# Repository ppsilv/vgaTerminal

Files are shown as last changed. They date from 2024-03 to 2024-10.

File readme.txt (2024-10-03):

A ultima versão do github ficou desatualizada ou por algum motivo que desconheço não funciona mais
Por conta de que a versão 0.0.04 parou de funcionar sem que eu entendesse oque aconteceu resolvi fazer uma nova versão com o mesmo hardware.

Eu desconfio que os problemas foram com as atualizações da lib do bitluni ESP32Lib, assim eu coloquei a lib no diretório da aplicação e em Arduino/libraries eu coloquei um link simbólico para a lib que agora faz parte do projeto, assim eu consigo ficar livre das atualizações que o bitluni está fazendo.

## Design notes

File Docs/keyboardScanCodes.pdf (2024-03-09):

Next (https://www.win.tue.nl/~aeb/linux/kbd/scancodes-2.html) Previous Contents (https://www.win.tue.nl/~aeb/linux/kbd/scancodes.html#toc1)

### 1. Keyboard scancodes

The data from a keyboard comes mainly in the form of scancodes, produced by key presses or used in the protocol with the computer. ( Different codes (https://www.win.tue.nl/~aeb/linux/kbd/scancodes-10.html#scancodesets) are used by the keyboard firmware internally, and there also exist several sets of scancodes. (https://www.win.tue.nl/~aeb/linux/kbd/scancodes-10.html#scancodesets) Here in this section we only talk about the default codes - those from translated scancode set
2. Less common modes are discussed below.) (https://www.win.tue.nl/~aeb/linux/kbd/scancodes-10.html#scancodesets) Each key press and key release produces between 0 and 6 scancodes.

### 1.1 Key release

Below I'll only mention the scancode for key press (`make'). The scancode for key release (`break') is obtained from it by setting the high order bit (adding 0x80 = 128). Thus, Esc press produces scancode 01, Esc release scancode 81 (hex). For sequences things are similar: Keypad-/ gives e0 35 when pressed, e0 b5 when released. Most keyboards will repeat the make code (key down code) when the key repeats. Some will also fake Shift down and Shift up events during the repeat.

The keys PrtSc/SysRq and Pause/Break are special. The former produces
scancode e0 2a e0 37 when no modifier key is pressed simultaneously, e0 37 together with Shift or Ctrl, but 54 together with (left or right) Alt. (And one gets the expected sequences upon release. But see below.) (https://www.win.tue.nl/~aeb/linux/kbd/scancodes-5.html#mtek) The latter produces scancode
sequence e1 1d 45 e1 9d c5 when pressed (without modifier) and nothing at all upon release. However, together with (left or right) Ctrl, one gets e0 46 e0 c6, and again nothing at release. It does not repeat.

See below (https://www.win.tue.nl/~aeb/linux/kbd/scancodes-1.html#dellnoup) for a report on keys with a different behaviour.

There are many reports of laptops with badly debounced key-up events. Thus, unexpected key-up events should probably be regarded as not unusual, and be ignored. Another source of key-up events without preceding key-down can be the fake shift. (https://www.win.tue.nl/~aeb/linux/kbd/scancodes-1.html#fakeshifts)

### 1.2 Protocol scancodes

Most scancodes indicate a key press or release. Some are used in the communication protocol.

00 Keyboard error - see ff
aa | BAT (Basic Assurance Test) OK

ee | Result of echo command
f1 | Some keyboards, as reply to command a4:Password not installed
fa | Acknowledge from kbd
fc | BAT error or Mouse transmit error
fd | Internal failure
fe | Keyboard fails to ack, please resend
ff | Keyboard error

Three common causes for keyboard error are: (i) several keys pressed simultaneously, (ii) keyboard buffer overflow, (iii) parity error on the serial line used by keyboard and keyboard controller for communication. The error reported is ff in scancode mode (https://www.win.tue.nl/~aeb/linux/kbd/scancodes-10.html#scancodesets) 1, and 00 in scancode modes 2 and 3. If translation is on, both 00 and ff are translated as ff.

Usually these codes have the protocol meaning. However, they also occur as actual scancodes, especially when prefixed by e0.

### 1.3 Escape scancodes

The codes e0 and e1 introduce scancode sequences, and are not usually used as isolated scancodes themselves (but see below). (https://www.win.tue.nl/~aeb/linux/kbd/scancodes-7.html#e0_as_key)
(The prefix e0 was originally used for the grey duplicates of keys on the original PC/XT keyboard. These days e0 is just used to expand code space. The prefix e1 used for Pause/Break indicated that this key sends the make/break sequence at make time, and does nothing upon release.)
This, and the above, means that the values 00, 60, 61, 6e, 71, 7a, 7c, 7e, 7f are unavailable to signify key presses (on a default keyboard). Nevertheless they also occur as scancodes, see for example the Telerate (https://www.win.tue.nl/~aeb/linux/kbd/scancodes-2.html#telerate) and Safeway SW23 (https://www.win.tue.nl/~aeb/linux/kbd/scancodes-6.html#safeway23) keyboards below.

Also other prefixes occur, see below. (https://www.win.tue.nl/~aeb/linux/kbd/scancodes-5.html#prefix_80)
Logitech (https://www.win.tue.nl/~aeb/linux/kbd/scancodes-10.html#logiteche2) uses an e2 prefix for the codes sent by a pointing device integrated on the keyboard.

### 1.4 Ordinary scancodes

The scancodes in translated scancode set 2 are given in hex. Between parentheses the keycap on a US keyboard. The scancodes are given in order, grouped according to groups of keys that are usually found next to each other.

### 00 is normally an error code

01 (Esc)

02 (1!), 03 (2@), 04 (3#), 05 (4$), 06 (5%E), 07 (6^), 08 (7&), 09 (8*), 0a (9(), 0b (0 )), 0c (-_), 0d (=+), 0e (Backspace)

0f (Tab), 10 (Q), 11 (W), 12 (E), 13 (R), 14 (T), 15 (Y), 16 (U), 17 (I), 18 (O), 19 (P), 1a ([{), 1b (]})

1c (Enter)

1d (LCtrl)

1e (A), 1f (S), 20 (D), 21 (F), 22 (G), 23 (H), 24 (J), 25 (K), 26 (L), 27 (;:), 28 ('")

29 (`~)

2a (LShift)

2b (\|), on a 102-key keyboard

2c (Z), 2d (X), 2e (C), 2f (V), 30 (B), 31 (N), 32 (M), 33 (,<), 34 (.>), 35 (/?), 36 (RS hift)
37 (Keypad-*) or (*/PrtScn) on a 83/84-key keyboard

38 (LAlt), 39 (Space bar),

3a (CapsLock)

3b (F1), 3c (F2), 3d (F3), 3e (F4), 3f (F5), 40 (F6), 41 (F7), 42 (F8), 43 (F9), 44 (F10 )
45 (NumLock)

46 (ScrollLock)

47 (Keypad-7/Home), 48 (Keypad-8/Up), 49 (Keypad-9/PgUp)

4a (Keypad--)

4b (Keypad-4/Left), 4c (Keypad-5), 4d (Keypad-6/Right), 4e (Keypad-+)

4f (Keypad-1/End), 50 (Keypad-2/Down), 51 (Keypad-3/PgDn)

52 (Keypad-0/Ins), 53 (Keypad-./Del)

54 (Alt-SysRq) on a 84+ key keyboard

### 55 is less common; occurs e.g. as F11 on a Cherry G80-0777 keyboard, as F12 on a

Telerate keyboard, as PF1 on a Focus 9000 keyboard, and as FN on an IBM ThinkPad.

56 mostly on non-US keyboards. It is often an unlabelled key to the left (https://www.win.tue.nl/~aeb/linux/kbd/laser.jpg) or to the right (https://www.win.tue.nl/~aeb/linux/kbd/toshiba.jpg) of the left Alt key.

57 (F11), 58 (F12) both on a 101+ key keyboard

59-5a-...-7f are less common. Assignment is essentially random. Scancodes 55-
59 occur as F11-F15 on the Cherry G80-0777 (https://www.win.tue.nl/~aeb/linux/kbd/scancodes-2.html#cherry80) keyboard. Scancodes 59-5c occur on the RC930 (https://www.win.tue.nl/~aeb/linux/kbd/scancodes-5.html#RC930) keyboard. X calls 5d `KEY_Begin'. Scancodes 61-64 occur on
a Telerate (https://www.win.tue.nl/~aeb/linux/kbd/scancodes-2.html#telerate) keyboard. Scancodes 55, 6d, 6f, 73, 74, 77, 78, 79, 7a, 7b, 7c, 7e occur on the Focus 9000 (https://www.win.tue.nl/~aeb/linux/kbd/scancodes-5.html#focus) keyboard. Scancodes 65, 67, 69, 6b occur on a Compaq
Armada (https://www.win.tue.nl/~aeb/linux/kbd/scancodes-5.html#armada) keyboard. Scancodes 66-68, 73 occur on the Cherry G81-3000 (https://www.win.tue.nl/~aeb/linux/kbd/scancodes-5.html#cherry81) keyboard. Scancodes 70, 73, 79, 7b, 7d occur on a Japanese 86/106 keyboard. (https://www.win.tue.nl/~aeb/linux/kbd/scancodes-8.html#japanese)

Scancodes f1 and f2 occur on Korean keyboards. (https://www.win.tue.nl/~aeb/linux/kbd/scancodes-9.html#korean)

### 1.5 Escaped scancodes

Apart from the Pause/Break key, that has an escaped sequence starting with e1, the escape used is e0. Often, the codes are chosen in such a way that something meaningful happens when the receiver just discards the e0.

e0 1c (Keypad Enter) | 1c (Enter)
e0 1d (RCtrl) | 1d (LCtrl)
e0 2a (fake LShift) | 2a (LShift)
e0 35 (Keypad-/) | 35 (/?)
e0 36 (fake RShift) | 36 (RShift)
e0 37 (Ctrl-PrtScn) | 37 (*/PrtScn)
e0 38 (RAlt) | 38 (LAlt)
e0 46 (Ctrl-Break) | 46 (ScrollLock)
e0 47 (Grey Home) | 47 (Keypad-7/Home)
e0 48 (Grey Up) | 48 (Keypad-8/UpArrow)
e0 49 (Grey PgUp) | 49 (Keypad-9/PgUp)
e0 4b (Grey Left) | 4b (Keypad-4/Left)
e0 4d (Grey Right) | 4d (Keypad-6/Right)
e0 4f (Grey End) | 4f (Keypad-1/End)
e0 50 (Grey Down) | 50 (Keypad-2/DownArrow)
e0 51 (Grey PgDn) | 51 (Keypad-3/PgDn)
e0 52 (Grey Insert) | 52 (Keypad-0/Ins)
e0 53 (Grey Delete) | 53 (Keypad-./Del)

These escaped scancodes occur only on 101+ key keyboards. The Microsoft keyboard (https://www.win.tue.nl/~aeb/linux/kbd/scancodes-6.html#microsoft) adds

e0 5b (LeftWindow)
e0 5c (RightWindow)
e0 5d (Menu)

Other escaped scancodes occur - see below under the individual keyboards.

### 1.6 Fake shifts

The ten grey keys Insert, Home, PgUp, Delete, End, PgDn, Up, Left, Down, Right are supposed to function regardless of the state of Shift and NumLock keys. But for an old AT keyboard the keypad keys would produce digits when Numlock was on or Shift was down. Therefore, in order to fool old programs, fake scancodes are sent: when LShift is down, and Insert is pressed, e0 aa e0 52 is sent; upon release of Insert e0 d2 e0 2a is sent. In other words, a fake LShift-up and fake LShift-down are inserted.

If the Shift key is released earlier than the repeated key, then a real Shift-up code occurs (without preceding fake Shift-down) so that a program ignoring e0 would see one more Shift-up than Shift-down.

When NumLock is on, no fake Shifts are sent when Shift was down, but fake Shifts are sent when Shift was not down. Thus, with Numlock, if Insert is
pressed, e0 2a e0 52 is sent and upon release e0 d2 e0 aa is sent. The keyboard maintains a private NumLock mode, toggled when NumLock is pressed, and set when the NumLock LED is set.

In the same way, when Shift is down, the Grey-/ key produces fake Shift-up and fake Shift-down sequences. However, it does not react to the state of NumLock. The purpose of course is to fool programs that identify Grey-/ with ordinary /, so that they don't treat Shift-Grey-/ like Shift-/, i.e., ?.

On a Toshiba notebook, the three Windows keys are treated like the group of ten keys mentioned, and get fake shifts when (left or right) Shift is down. They do not react to NumLock.

### 1.7 Added non-fake shifts

On my 121-key Nokia Data (https://www.win.tue.nl/~aeb/linux/kbd/scancodes-5.html#nokia) keyboard there are function keys F1, ..., F24, where F1, ..., F12 send the expected codes 3b, ..., 58, and F13, ..., F24 send the same codes

together with the LShift code 2a. Thus, F13 gives 2a 3b on press, and bb aa on release. Similarly, there are keys with added LCtrl code 1d. But there are also keys with added fake shifts e0 2a.
Delorie (http://www.delorie.com/djgpp/doc/rbinter/it/06/0.html) reports that the "Preh Commander AT" keyboard with additional F11-F22

## keys treats F11-F20 as Shift-F1..Shift-F10 and F21/F22 as Ctrl-F1/Ctrl-F2; the

Eagle PC-2 keyboard with F11-F24 keys treats those additional keys in the same way.

### 1.8 Turbo Mode

On some motherboards the LCtrl-LAlt-GreyPlus and LCtrl-LAlt-GreyMinus switch Turbo mode on/off, respectively. For these, the motherboard may generate the same scancode sequence when the Turbo button is pushed: Turbo Switch (High-
>Low): 1d 38 4a ce b8 9d and Turbo Switch (Low->High): 1d 38 4e ce b8 9d.

Other peculiar combinations in this style include LCtrl-LAlt-LShift-GreyMinus and LCtrl-LAlt-LShift-GreyPlus to turn system cache off/on.

If Green PC system power saving mode is enabled in AMIBIOS Setup, the AMI MegaKey keyboard controller recognizes the combinations Ctrl-Alt-\ (put the system into immediate power down mode), Ctrl-Alt-[ (disable the Green PC power savings mode temporarily), Ctrl-Alt-] (enables the Green PC power down mode).

Thio Yu Jin <jin@singmail.com> complains that on his Toshiba 4010CDS the Ctrl-Alt-Shift-T key combination brings up the Toshiba user manual. (04 Mar 1999 - not April 1.)

### 1.9 Power Saving

Microsoft (http://www.microsoft.com/hwdev/tech/input/Scancode.asp) recommends: "i8042-based keyboards should deploy the following scan codes for power management buttons, i.e., POWER and SLEEP buttons:

Set-1 make/break | Set-2 make/break
Power | e0 5e / e0 de | e0 37 / e0 f0 37
Sleep | e0 5f / e0 df | e0 3f / e0 f0 3f
Wake | e0 63 / e0 e3 | e0 5e / e0 f0 5e

The Power, Sleep, and Wake event scan codes are the i8042 equivalents to the System Power Down, System Sleep, and System Wake Up HID usages".

Many keyboards have Power/Sleep/Wake keys that have to be activated by a fourth key (unlabeled, or labeled FN): pressing one of these four keys does not produce any scancodes, but when the FN key is pressed simultaneously, the Power/Sleep/Wake keys give the codes listed above.

### 1.10 Initializing special keyboards

Many keyboards have more keys and buttons than the standard ones. Sometimes these additional keys produce scancode combinations that were unused before. But on other keyboard such additional keys do not produce any code at all, until some initializing action is taken.

Sometimes that action consists of writing some bytes to keyboard registers. See, for example, the IBM Rapid Access keyboard, (https://www.win.tue.nl/~aeb/linux/kbd/scancodes-6.html#rapidinit) and the Omnibook keyboard. (https://www.win.tue.nl/~aeb/linux/kbd/scancodes-6.html#omnibookinit)

### 1.11 Manipulating extra LEDs

Some keyboards have additional LEDs, and in a few cases we know how to manipulate those.
The Chicony keyboard (https://www.win.tue.nl/~aeb/linux/kbd/scancodes-6.html#chicony) needs command sequences eb 00 xy, with xy = 01 for the Moon LED and xy = 02 for the zzZ LED.

The IBM EZ Button keyboard (https://www.win.tue.nl/~aeb/linux/kbd/scancodes-6.html#EZButton) needs command sequences eb 00 xy, with xy = 01 for the Msg LED, xy = 02 for the CD LED, xy = 04 for the Power LED, xy = 10 for the Talk LED, and xy = 20 for the Message Waiting LED.

The IBM Rapid Access keyboard (https://www.win.tue.nl/~aeb/linux/kbd/scancodes-6.html#ibmrapidaccess) needs command sequences eb 00 xy,
with xy = 04 for the Suspend LED and xy = 20 for the Mute LED.

The IBM Rapid Access keyboard II (https://www.win.tue.nl/~aeb/linux/kbd/scancodes-6.html#ibmrapidaccessii) needs the command
sequences eb 71 and eb 70 to switch the Standby LED on and off.

The Logitech Internet Keyboard (https://www.win.tue.nl/~aeb/linux/kbd/scancodes-6.html#logitechinternet) has an additional amber LED. It is turned on by sending eb, and then blinks about once a second. It is turned off again by ec.

### 1.12 The laptop FN key

Laptops have no room for all nonsensical keys one usually find on a regular keyboard. So, the number pad and other keys are folded into the main part of the keyboard. A key without label, or labelled FN is often used to modify the meaning of other keys. This FN does not produce scancodes itself, it only modifies the scancodes produced by other keys.

Neil Brown reports about his Dell Latitude D800 laptop that it has five key combinations that do not produce proper break codes. The five combinations FN+F2, FN+F3, FN+F10, FN+Down, FN+Up (labelled Wireless, Brighter, Darker, Battery,

CDEject) produce make codes e0 08, e0 07, e0 09, e0 05, e0 06, respectively. The first three do not produce any break code. The last two have a break code that is identical to the make code.

Next (https://www.win.tue.nl/~aeb/linux/kbd/scancodes-2.html) Previous Contents (https://www.win.tue.nl/~aeb/linux/kbd/scancodes.html#toc1)

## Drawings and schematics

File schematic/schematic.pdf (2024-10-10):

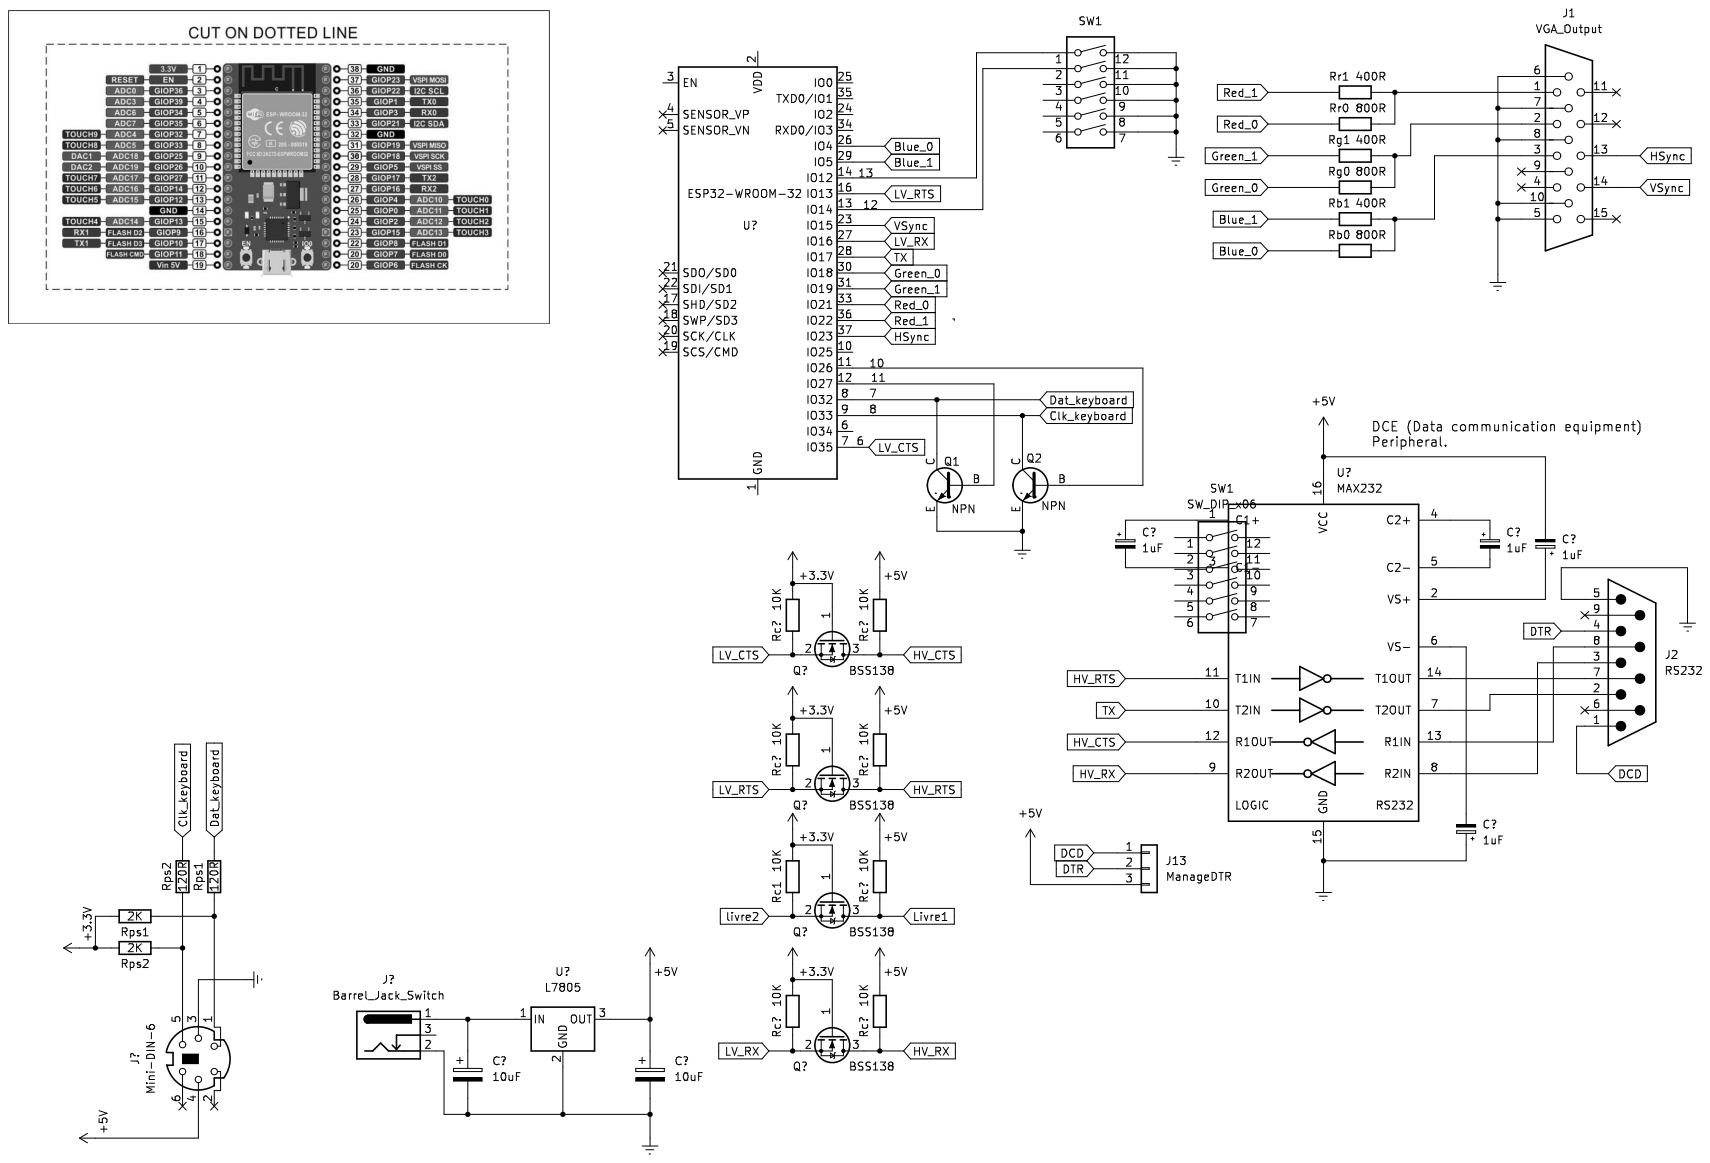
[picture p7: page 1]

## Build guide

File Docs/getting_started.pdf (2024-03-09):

This board is handmade: except for the cost of components, every cent will be reinvested to improve the FabGL library, applications and to produce even better boards.

This board comes preprogrammed with the Ansi Terminal application. It can be used as TTL UART terminal or RS232 terminal.
You may need a NULL-Modem cable or adapter to use this board as classic computer terminal.

In case you need to reprogram the board (external programmer required) follow these steps:

1) Install the current upstream Arduino IDE at the 1.8 level or later. The current version is at the arduino.cc (https://www.arduino.cc/en/Main/Software) website.
2) Start Arduino and open the Preferences window.
3) Into Additional Board Manager URLs field enter:

"https://raw.githubusercontent.com/espressif/arduino-esp32/gh-pages/package_esp32_index.json"

4) Open Boards Manager from Tools > Boards Manager... menu and install esp32 platform
5) From Tools menu select the board "ESP32 Dev Module". In the board menu, set following parameters:
- Upload speed: 460800
- Partition Scheme: Huge App
6) Open Tools > Manage Libraries menu and install fabgl library.
7) Restart Arduino IDE.
8) Open File > Examples > FabGL menu to select one of the FabGL examples.

The Board

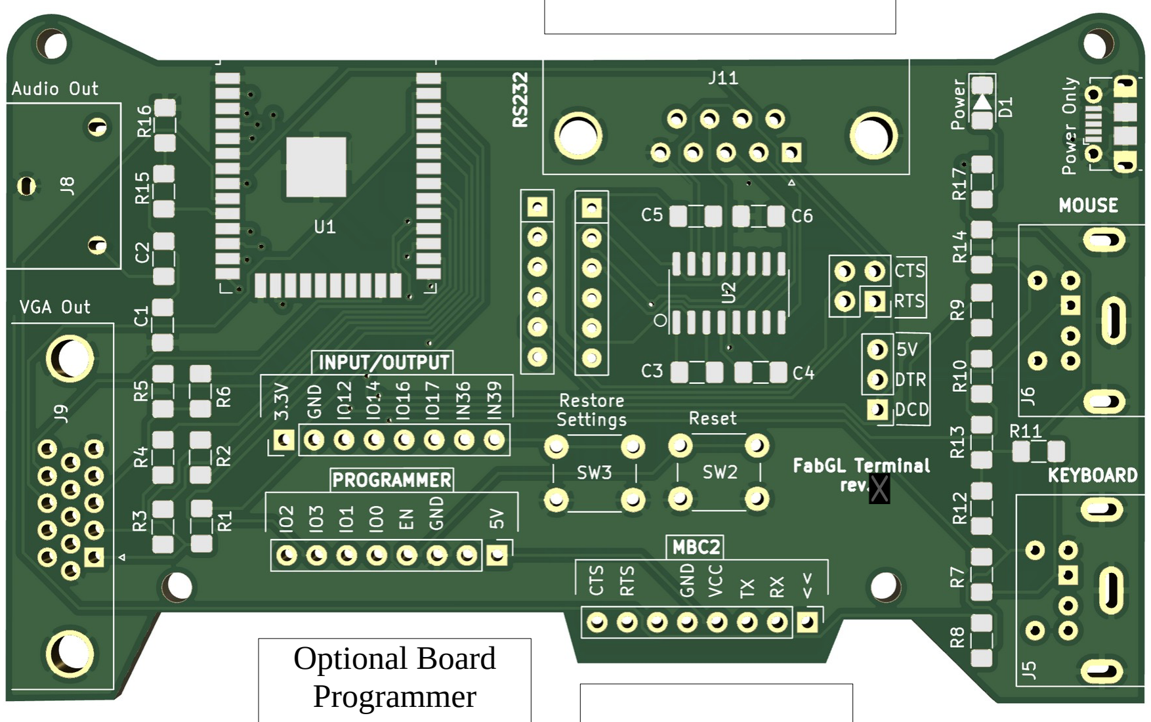
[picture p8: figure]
Optional Board Programmer

Notes:

- RS232 and TTL UART share the same communication channel, so just one at the time can be used
- to reset the Terminal settings, keep pressed "Restore Settings" while powering on the board
- USB on the board is just for Power, not for programming
- when a programmer board is inserted, disconnect any USB cable connected to the board
- RS232 implements following signals: TX, RX, CTS, RTS.
- DTR is directly connected to DCD. However it can be connected to 5V changing the related jumper.

U
S
B

F
or P

o
wer

o
nly

P
S/2

P
ort 0

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
ort 1

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
ut A

u

dio

O

utp

ut
Line Level

RS232

TTL UART
(MBC2 compatible)

Block Diagram and GPIO Assignments

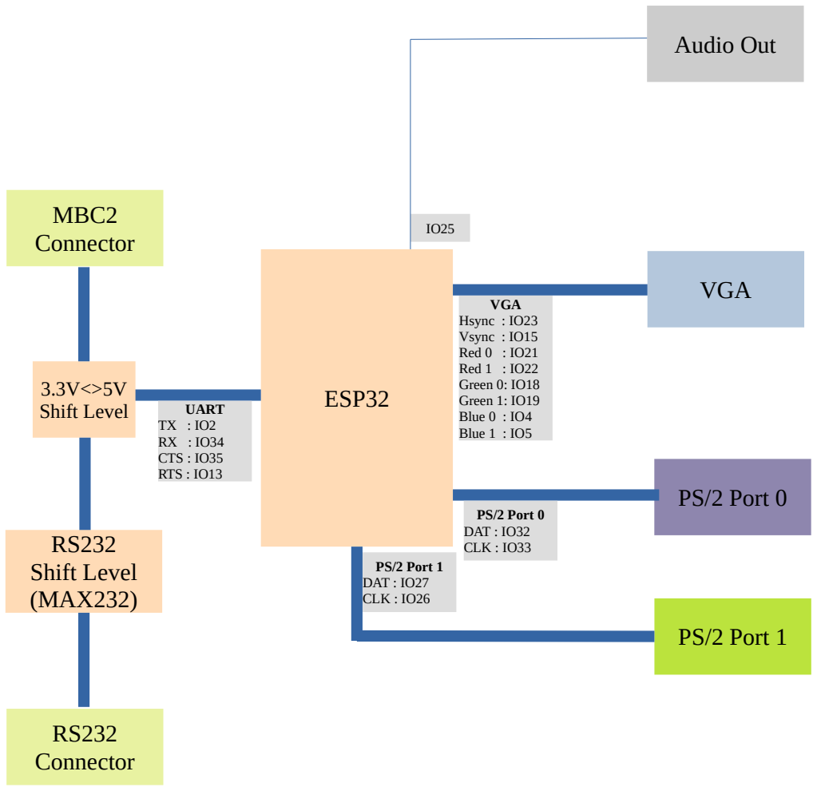
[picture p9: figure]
ESP32; Audio Out; VGA; PS/2 Port 0; PS/2 Port 1; VGA Hsync : IO23 Vsync : IO15 Red 0 : IO21 Red 1 : IO22 Green 0: IO18 Green 1: IO19 Blue 0 : IO4 Blue 1 : IO5; PS/2 Port 0 DAT : IO32 CLK : IO33; PS/2 Port 1 DAT : IO27 CLK : IO26; UART TX : IO2 RX : IO34 CTS : IO35 RTS : IO13; 3.3V<>5V Shift Level; MBC2 Connector; RS232 Shift Level (MAX232); RS232 Connector

References

- Library Source Code: https://github.com/fdivitto/FabGL
- Library Documentation: http://www.fabgl.com
- YouTube Channel: https://www.youtube.com/c/fdivitto/videos

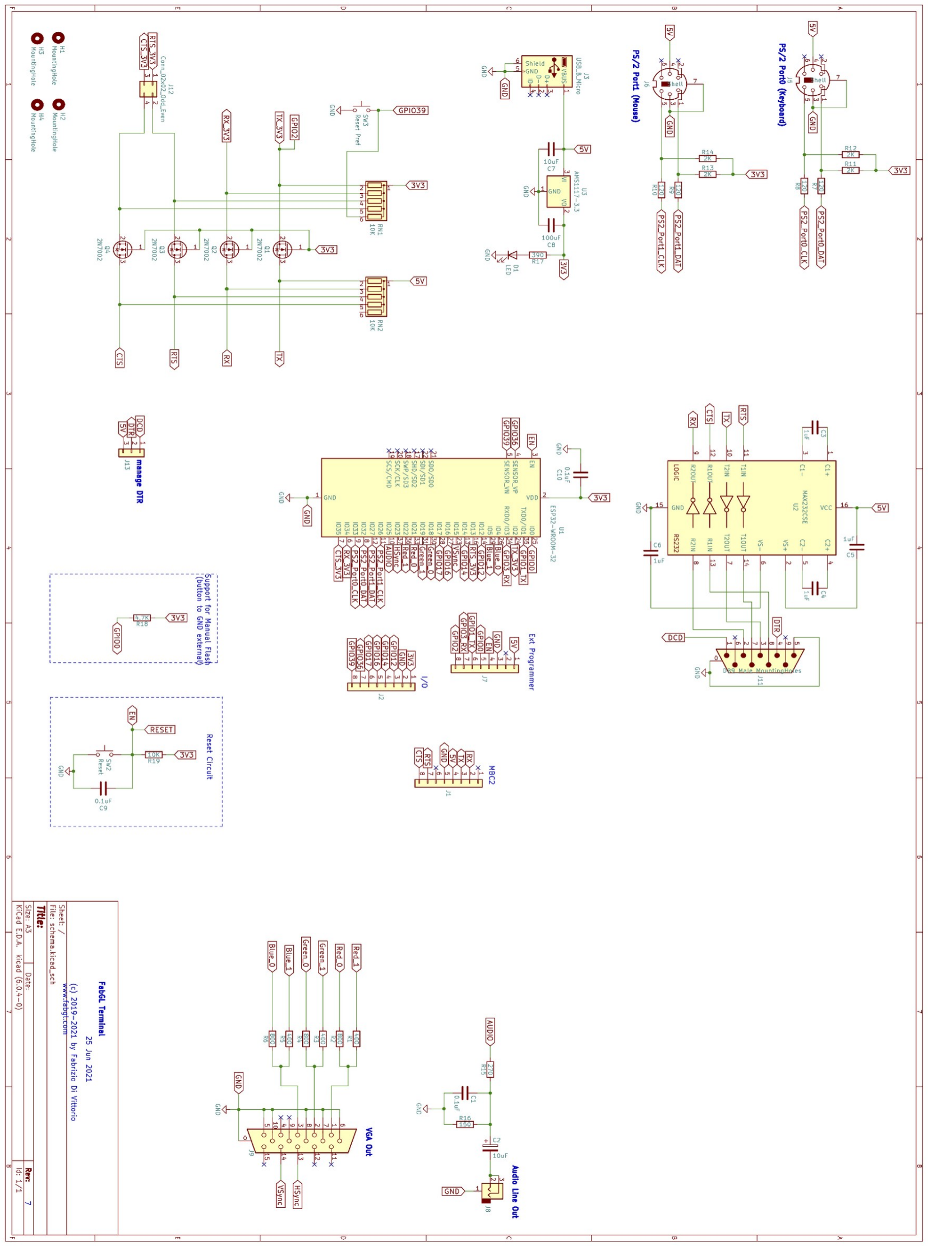
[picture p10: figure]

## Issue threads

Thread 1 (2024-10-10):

Sistema reseta automaticamente

ppsilv, 2024-10-10:
No preenchimento total da tela com caracteres, após digitar o último caractere que que preenche a tela o sistema reseta.
O problema está em digitar enter na última linha ou preenche-la totalmente para passar para a próxima.

ppsilv, 2024-10-12:
O que está provocando o erro de reset nessa situação é o sistema de cursor criado com interrupção do timer.
Como eu não achei o motivo e tenho pressa vai ficar para uma outra ocasião essa resolução.

ppsilv, 2024-10-12:
O problema era a função chamada para limpar o cursor antes da escrita de um caractere clearCursor que estava chamando fastDot quando deveria chamar dot().

Closed 2024-10-12.

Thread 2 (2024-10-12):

O primeiro caractere da primeira linha após começar o scroll.

ppsilv, 2024-10-12:
Toda vez que o começa um scroll o primeiro caractere da primeira linha não é impresso corretamente, e sem as gambiarras que eu criei todo primeiro caractere de cada linha quando em scroll não é impresso na tela.
Com a gambiarra que fiz ele é mostrado parcialmente na primeira linha e corretamente em todas as ouras.
O código do luni é muito complexo sem necessidade por isso está difícil descobrir o problema.

ppsilv, 2024-10-12:
O problema é com a referência para a cópia de buffers para fazer o scroll, não entendi a lógica usada, a gambiarra que fiz sincroniza a cópia para a segunda linha e as subsequêntes, mas o caractere da primeira linha após o scroll fica comprometido.

Closed 2024-10-15.

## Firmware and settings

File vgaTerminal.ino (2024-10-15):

/*
  Autor: Paulo da Silva
  Data.: 02/10/2024
  Versão: 0.1.00 
          A versão 0.1.00 foi aproveitado os códigos Serial0,PS2Keyboard e Terminal e o
          código vgaTerminal foi totalmente refeito, pois a versão 0.0.04 não estava compilando
          
*/
#include "esp32lib.h"
#include <Ressources/Font6x8.h>
#include <Ressources/CodePage437_8x8.h>
#include "Serial0.h"
#include "PS2Keyboard.h"
#include "Terminal.h"

//pin configuration
const int redPin = 22;
const int greenPin = 19;
const int bluePin = 5;
const int hsyncPin = 23;
const int vsyncPin = 15;

//VGA Device
//VGA1BitI vga;
VGA3Bit vga;
//Serial
TSerial0 *serial0 = TSerial0::getInstance();
//Keyboard
PS2Keyboard keyboard;
//Terminal
Terminal terminal;

extern void setupTimer();

const uint8_t frontColors[] = {0x2,0x0,0x1,0x4,0x1,0x7,0x3,0x3};
const uint8_t backColors[] = {0x0,0x7,0x0,0x6,0x7,0x0,0x4,0x4};

char * versao = "2.0.00";
char * screenMode = "640x400";
int baudrate = serial0->getBaud() ;
char * uartConfig = "8N1";
char * keyboardType = "US-Keyboard";

extern void loopTimer();
extern uint16_t myCOLORS[7];

void header()
{
  vga.setTextColor(myCOLORS[AMARELO]);             
  vga.print("         1          2         3         4         5         6         7         ");
	vga.print("01234567890123456789012345678901234567890123456789012345678901234567890123456789");
  vga.setTextColor(myCOLORS[VERMELHO]);             
	vga.print("               ******* Open  Software - Copyright (C) 2024 *******\n");
  vga.setTextColor(myCOLORS[VERDE]);             
	vga.print("Terminal serial.: Versao ");vga.println((const char *)versao);
  vga.print("Screen mode.....: ");vga.println((const char *)screenMode);
  vga.print("Serial..........: ");vga.print(baudrate); vga.print("-"); vga.println((const char *)uartConfig);//serial0->getBaud();vga.println("-8N1" );
  vga.print("Keyboard........: ");vga.println((const char *)keyboardType);
  vga.print("Cursor..........: ");terminal.showCursorCursorStatus();
	vga.print("Free memory.....: ");vga.println((int)heap_caps_get_free_size(MALLOC_CAP_DEFAULT));
  vga.print("********************************************************************************\n");  
}
extern void setupCursor();
extern void treatCursor();

void setup()
{
  Serial.begin(115200);
	//initializing vga at the specified pins
  if ( memcmp(screenMode,"640x400",7 ) == 0 ){
	  vga.init(vga.MODE640x350, redPin, greenPin, bluePin, hsyncPin, vsyncPin);
  }else if ( memcmp(screenMode,"320x200",7 ) == 0 ){
    vga.init(vga.MODE320x200, redPin, greenPin, bluePin, hsyncPin, vsyncPin);
  }
  //vga.setResolution(640,  200);
	//selecting the font
  vga.setFont(CodePage437_8x8);
  vga.clear();
  delay(500);
  vga.setCursor(0,0);
  vga.setTextColor(myCOLORS[VERDE]);             
	//vga.setFrontGlobalColor(0,255,0);
	//vga.setBackGlobalColor(0,0,0);  

  //Serial0 
  serial0->begin(); 
  //Keyboard
  keyboard.begin(); 
	if (keyboard.WaitForKeyboard() == false)
	{
		Serial.write("Keyboard not found... \nPress F1 to continue\n \nStoped......");
		while (1);
	}
	keyboard.setNumLock();
  //Initialization Completed
  Serial.printf("Buffer size: [%02d]\n",keyboard.GetBufferSize());
  
  //setupTimer();

  Serial.write("Initialization Completed\n");
  delay(1000);
 
  vga.setCursorText(0,0);
  vga.setTextColor(myCOLORS[VERDE]);             

  //Print terminal header
  header();
  setupCursor();
}

void loop()
{
  terminal.run();  
  keyboard.verifyStatus();
  treatCursor();
}

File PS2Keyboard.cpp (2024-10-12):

#include <Arduino.h>
#include "PS2Keyboard.h"



const PS2Keymap_t *keymap=NULL;

#define TransistorIRQPin  26
#define TransistorDataPin 27
#define DataPin     32
#define IRQPin      33
//Oito estados para a varialvel uint8_t state
#define BREAK     0x01
#define MODIFIER  0x02
#define SHIFT_L   0x04
#define SHIFT_R   0x08
#define ALTGR     0x10
#define SCROLL    0x20
#define NUMLOCK   0x40
#define CAPS      0x80


extern void hnd(void);

PS2Keyboard* PS2Keyboard::keyboard0Ptr;
/*
PS2Keyboard* PS2Keyboard::keyboard1Ptr;
PS2Keyboard* PS2Keyboard::keyboard2Ptr;
PS2Keyboard* PS2Keyboard::keyboard3Ptr;                              
PS2Keyboard* PS2Keyboard::keyboard4Ptr;
PS2Keyboard* PS2Keyboard::keyboard5Ptr;
PS2Keyboard* PS2Keyboard::keyboard6Ptr;
PS2Keyboard* PS2Keyboard::keyboard7Ptr;
*/
const char chrsNS[]={
    0,    249,  0,    245,  243,  241,  242,  252,  0,    250,  248,  246,  244,  '\t', '`',  0,
    0,    0,    0,    0,    0,    'q',  '1',  0,    0,    0,    'z',   's',  'a',  'w',  '2',  0,
    0,    'c',  'x',  'd',  'e',  '4',  '3',  0,    0,    ' ',  'v',  'f',  't',  'r',  '5',  0,
    0,    'n',  'b',  'h',  'g',  'y',  '6',  0,    0,    0,    'm',  'j',  'u',  '7',  '8',  0,
    0,    ',',  'k',  'i',  'o',  '0',  '9',  0,    0,    '.',  '/',  'l',  ';',  'p',  '-',  0,
    0,    0,    '\'', 0,    '[',  '=',  0,    0,    0,    0,    '\n', ']',  0,    '\\', 0,    0,
    0,    0,    0,    0,    0,    0,    '\b', 0,    0,    '1',  0,    '4',  '7',  0,    0,    0,
    '0',  '.',  '2',  '5',  '6',  '8',  '\033',0,   251,  '+',  '3',  '-',  '*',  '9',  0,    0,
    0,    0,    0,    247,  0,    0,    0,    0,    0,    0,    0,    0,    0,    0,    0,    0};

const char chrsSH[]={
    0,    249,  0,    245,  243,  241,  242,  252,  0,    250,  248,  246,  244,  '\t', '~',  0,
    0,    0,    0,    0,    0,    'Q',  '!',  0,    0,    0,    'Z',  'S',  'A',  'W',  '@',  0,
    0,    'C',  'X',  'D',  'E',  '$',  '#',  0,    0,    ' ',  'V',  'F',  'T',  'R',  '%',  0,
    0,    'N',  'B',  'H',  'G',  'Y',  '^',  0,    0,    0,    'M',  'J',  'U',  '&',  '*',  0,
    0,    '<',  'K',  'I',  'O',  ')',  '(',  0,    0,    '>',  '?',  'L',  ':',  'P',  '_',  0,
    0,    0,    '\"', 0,    '{',  '+',  0,    0,    0,    0,    '\n', '}',  0,    '|',  0,    0,
    0,    0,    0,    0,    0,    0,    '\b', 0,    0,    '1',  0,    '4',  '7',  0,    0,    0,
    '0',  '.',  '2',  '5',  '6',  '8',  '\033',0,   0,    '+',  '3',  '-',  '*',  '9',  0,    0,
    0,    0,    0,    247,  0,    0,    0,    0,    0,    0,    0,    0,    0,    0,    0,    0};

const char chrsSH1[]={
    0,    249,  0,    245,  243,  241,  242,  252,  0,    250,  248,  246,  244,  '\t', '~',  0,
    0,    0,    0,    0,    0,    'q',  '!',  0,    0,    0,    'z',  's',  'a',  'w',  '@',  0,
    0,    'c',  'x',  'd',  'e',  '$',  '#',  0,    0,    ' ',  'v',  'f',  't',  'r',  '%',  0,
    0,    'n',  'b',  'h',  'g',  'y',  '^',  0,    0,    0,    'm',  'j',  'u',  '&',  '*',  0,
    0,    '<',  'k',  'i',  'O',  ')',  '(',  0,    0,    '>',  '?',  'l',  ':',  'p',  '_',  0,
    0,    0,    '\"', 0,    '{',  '+',  0,    0,    0,    0,    '\n', '}',  0,    '|',  0,    0,
    0,    0,    0,    0,    0,    0,    '\b', 0,    0,    '1',  0,    '4',  '7',  0,    0,    0,
    '0',  '.',  '2',  '5',  '6',  '8',  '\033',0,   0,    '+',  '3',  '-',  '*',  '9',  0,    0,
    0,    0,    0,    247,  0,    0,    0,    0,    0,    0,    0,    0,    0,    0,    0,    0};


#define BUFFER_SIZE 256
static volatile uint8_t buffer[BUFFER_SIZE];
static volatile uint8_t head, tail;


static volatile uint8_t SendByteState;
static volatile byte    SendBits[10];
static volatile uint8_t disableisr;
static volatile uint8_t fulldisableisr;
static volatile uint16_t waitcounter;

bool bs = false;
bool tab = false;


volatile uint8_t state=0;
volatile bool capsChanged=false;
volatile bool numChanged=false;

#pragma GCC push_options
#pragma GCC optimize ("O2")

int PS2Keyboard::GetBufferSize()
{
  return(sizeof(buffer));
}

byte PS2Keyboard::GetParity(byte b)
{
	byte count = 0;
	for (byte i = 0; i < 8; i++)
	{
		if (((b >> i) & 0x1) == 1)
			count++;
	}
	return ((count % 2) == 1 ? 0 : 1);
}

void PS2Keyboard::SendByte(byte b)
{
	SendBits[0] = 1;

	for (byte j = 0; j < 8; j++)
		SendBits[j + 1] = ((b >> j) & 0x1) == 0x1 ? 0x0 : 0x1;

	SendBits[9] = GetParity(b) == 0x1 ? 0x0 : 0x1;

	SendByteState  = 0;
	fulldisableisr = 1;
	digitalWrite(TransistorIRQPin, 1);
	delayMicroseconds(100);
	digitalWrite(TransistorDataPin, 1);
	delayMicroseconds(100);
	digitalWrite(TransistorIRQPin, 0);
	disableisr = 1;
	fulldisableisr = 0;

	while (disableisr != 0); //Aguarda a interrupção transmitir

	delay(10);
}
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

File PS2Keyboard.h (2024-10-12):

#ifndef __PS2KEYBOARD_H__
#define __PS2KEYBOARD_H__
#include <cstdint>

// Every call to read() returns a single byte for each
// keystroke.  These configure what byte will be returned
// for each "special" key.  To ignore a key, use zero.
#define PS2_TAB				  9
#define PS2_ENTER       13
#define PS2_BACKSPACE		127
#define PS2_ESC				  27
#define PS2_INSERT			0
#define PS2_DELETE			127
#define PS2_HOME			  0
#define PS2_END				  0
#define PS2_PAGEUP			25
#define PS2_PAGEDOWN		26
#define PS2_UPARROW			11
#define PS2_LEFTARROW		8
#define PS2_DOWNARROW		10
#define PS2_RIGHTARROW  21
#define PS2_F1				0
#define PS2_F2				0
#define PS2_F3				0
#define PS2_F4				0
#define PS2_F5				0
#define PS2_F6				0
#define PS2_F7				0
#define PS2_F8				0
#define PS2_F9				0
#define PS2_F10				0
#define PS2_F11				0
#define PS2_F12				0
#define PS2_SCROLL			0
#define PS2_EURO_SIGN			0

#define PS2_INVERTED_EXCLAMATION	161 // ¡
#define PS2_CENT_SIGN			        162 // ¢
#define PS2_POUND_SIGN			      163 // £
#define PS2_CURRENCY_SIGN		      164 // ¤
#define PS2_YEN_SIGN			        165 // ¥
#define PS2_BROKEN_BAR            166 // ¦
#define PS2_SECTION_SIGN          167 // §
#define PS2_DIAERESIS             168 // ¨
#define PS2_COPYRIGHT_SIGN        169 // ©
#define PS2_FEMININE_ORDINAL      170 // ª
#define PS2_LEFT_DOUBLE_ANGLE_QUOTE	171 // «
#define PS2_NOT_SIGN			172 // ¬
#define PS2_HYPHEN			173
#define PS2_REGISTERED_SIGN		174 // ®
#define PS2_MACRON			175 // ¯
#define PS2_DEGREE_SIGN			176 // °
#define PS2_PLUS_MINUS_SIGN		177 // ±
#define PS2_SUPERSCRIPT_TWO		178 // ²
#define PS2_SUPERSCRIPT_THREE		179 // ³
#define PS2_ACUTE_ACCENT		180 // ´
#define PS2_MICRO_SIGN			181 // µ
#define PS2_PILCROW_SIGN		182 // ¶
#define PS2_MIDDLE_DOT			183 // ·
#define PS2_CEDILLA			184 // ¸
#define PS2_SUPERSCRIPT_ONE		185 // ¹
#define PS2_MASCULINE_ORDINAL		186 // º
#define PS2_RIGHT_DOUBLE_ANGLE_QUOTE	187 // »
#define PS2_FRACTION_ONE_QUARTER	188 // ¼
#define PS2_FRACTION_ONE_HALF		189 // ½
#define PS2_FRACTION_THREE_QUARTERS	190 // ¾
#define PS2_INVERTED_QUESTION_MARK	191 // ¿
#define PS2_A_GRAVE			192 // À
#define PS2_A_ACUTE			193 // Á
#define PS2_A_CIRCUMFLEX		194 // Â
#define PS2_A_TILDE			195 // Ã
#define PS2_A_DIAERESIS			196 // Ä
#define PS2_A_RING_ABOVE		197 // Å
#define PS2_AE				198 // Æ
#define PS2_C_CEDILLA			199 // Ç
#define PS2_E_GRAVE			200 // È
#define PS2_E_ACUTE			201 // É
#define PS2_E_CIRCUMFLEX		202 // Ê
#define PS2_E_DIAERESIS			203 // Ë
#define PS2_I_GRAVE			204 // Ì
#define PS2_I_ACUTE			205 // Í
#define PS2_I_CIRCUMFLEX		206 // Î
#define PS2_I_DIAERESIS			207 // Ï
#define PS2_ETH				208 // Ð
#define PS2_N_TILDE			209 // Ñ
#define PS2_O_GRAVE			210 // Ò
#define PS2_O_ACUTE			211 // Ó
#define PS2_O_CIRCUMFLEX		212 // Ô
#define PS2_O_TILDE			213 // Õ
#define PS2_O_DIAERESIS			214 // Ö
#define PS2_MULTIPLICATION		215 // ×
#define PS2_O_STROKE			216 // Ø
#define PS2_U_GRAVE			217 // Ù
#define PS2_U_ACUTE			218 // Ú
#define PS2_U_CIRCUMFLEX		219 // Û
#define PS2_U_DIAERESIS			220 // Ü
#define PS2_Y_ACUTE			221 // Ý
#define PS2_THORN			222 // Þ
#define PS2_SHARP_S			223 // ß
#define PS2_a_GRAVE			224 // à
#define PS2_a_ACUTE			225 // á
#define PS2_a_CIRCUMFLEX		226 // â
#define PS2_a_TILDE			227 // ã
#define PS2_a_DIAERESIS			228 // ä
#define PS2_a_RING_ABOVE		229 // å
#define PS2_ae				230 // æ
#define PS2_c_CEDILLA			231 // ç
#define PS2_e_GRAVE			232 // è
#define PS2_e_ACUTE			233 // é
#define PS2_e_CIRCUMFLEX		234 // ê
#define PS2_e_DIAERESIS			235 // ë
#define PS2_i_GRAVE			236 // ì
#define PS2_i_ACUTE			237 // í
#define PS2_i_CIRCUMFLEX		238 // î
#define PS2_i_DIAERESIS			239 // ï
#define PS2_eth				240 // ð
#define PS2_n_TILDE			241 // ñ
#define PS2_o_GRAVE			242 // ò
#define PS2_o_ACUTE			243 // ó
#define PS2_o_CIRCUMFLEX		244 // ô
#define PS2_o_TILDE			245 // õ
#define PS2_o_DIAERESIS			246 // ö
#define PS2_DIVISION			247 // ÷
#define PS2_o_STROKE			248 // ø
#define PS2_u_GRAVE			249 // ù
#define PS2_u_ACUTE			250 // ú
#define PS2_u_CIRCUMFLEX		251 // û
#define PS2_u_DIAERESIS			252 // ü
#define PS2_y_ACUTE			253 // ý
#define PS2_thorn			254 // þ
#define PS2_y_DIAERESIS			255 // ÿ


#define PS2_KEYMAP_SIZE 136

typedef struct {
	uint8_t noshift[PS2_KEYMAP_SIZE];
	uint8_t shift[PS2_KEYMAP_SIZE];
	uint8_t capsshift[PS2_KEYMAP_SIZE];
	unsigned int uses_altgr;
    /*
     * "uint8_t uses_altgr;" makes the ESP8266 - NodeMCU modules crash.
     * So, I replaced it with an int and... It works!
     * I think it's because of the 32-bit architecture of the ESP8266
     * and the use of the flash memory to store the keymaps.
     * Maybe I'm wrong, it remains a hypothesis.
     */
	uint8_t altgr[PS2_KEYMAP_SIZE];
} PS2Keymap_t;

#include "KeybLayout.h"
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

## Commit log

2024-03-13 esp32lib clean up
2024-03-15 Implemented led caps and numlock
2024-03-16 V 0.0.02 fixed enter trespassing line 42
    [Graphics.h, Terminal.cpp, vgaTerminal.ino]
2024-03-16 V 0.0.03 - fixed cursor
    [Graphics.h, Serial0.cpp, Terminal.cpp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]
2024-03-22 fixed max232 cap acitor pin 2 was inverted
    [AnsiTerminal.kicad_sch]
2024-10-03 Fixed: the char from keyboard and printed into linux terminal are correct now after changed ESP32 to serial2
    [vgaTerminal.ino]
2024-10-03 Fixed: The TX pin goes directly from the CPU to the RS232 chip
    [AnsiTerminal.kicad_sch]
2024-10-10 Versao 1.0.00
    [AnsiTerminal.kicad_sch]
2024-10-12 Fixed: ordem das cores
    [Terminal.cpp]
2024-10-14 Corrigido o erro de scroll
    [Graphics.h, Terminal.cpp, vgaTerminal.ino]
